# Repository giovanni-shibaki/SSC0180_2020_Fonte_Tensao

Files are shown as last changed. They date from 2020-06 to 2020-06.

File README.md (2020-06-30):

# SSC0180_2020_Fonte_Tensao
Projeto de estudo e desenvolvimento de uma fonte elétrica na matéria de SSC0180 USP 2020. Vamos partir da tensão da tomada (220V ou 127V) e teremos que transforma-la de 127V/220V Corrente Alternada em uma tensão adequada para alimentar nosso circuito. Isto é, de 3V-12V em Corrente Contínua.

## Diagrama da Fonte
### No Falstad
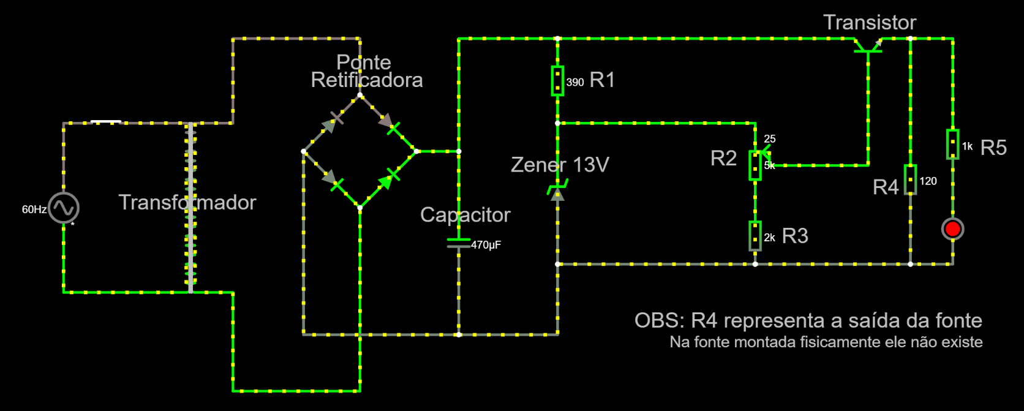
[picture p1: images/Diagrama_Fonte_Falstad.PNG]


### Critérios
* Tensão ajustável entre 3V e 12V 
* Corrente de 100mA
* Baixo Custo

### Componentes e seus Valores
| Componente | Especificações | Valor (Unidade)|
| :--- | :---: | :---  |
| Resistor | 120Ω | [R$0,86](https://tinyurl.com/y8pryj5b) |
| Resistor | 390Ω | [R$0,30](https://produto.mercadolivre.com.br/MLB-1008875897-kit-100un-resistores-2w-de-potncia-escolha-1-valor-ohmico-_JM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) |
| Resistor | 1kΩ | [R$0,13](https://produto.mercadolivre.com.br/MLB-1399314776-resistor-1k-ohms-100-unidades-_JM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) |
| Resistor | 2kΩ | [R$0,16](https://produto.mercadolivre.com.br/MLB-1359755617-100un-resistor-18w-2k-2000-ohms-_JM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) |
| Potenciômetro | 5kΩ | [R$1,09](https://www.baudaeletronica.com.br/potenciometro-linear-de-5k-5000.html) |
| Capacitor | 470μF | [R$1,70](https://produto.mercadolivre.com.br/MLB-845022301-10x-capacitor-eletrolitico-470uf-x-25v-470-uf-470uf-b-_JM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) |
| Transistor | 15V  e 500mA | [R$1,12](https://produto.mercadolivre.com.br/MLB-939476869-10x-transistor-2sa1015-a1015-_JM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) |
| Diodo de Zener | 0,5W | [R$0,21](https://produto.mercadolivre.com.br/MLB-1395521239-diodo-zener-13v-05w-1n5243-lote-de-100-pecas-_JM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) |
| Ponte Retificadora| 1000V e 2A | [R$1,96](https://produto.mercadolivre.com.br/MLB-1151520283-ponte-retificadora-2w10-2a-1000v-lote-com-10-pecas-_JM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) |
| Transformador | 15V e 500mA | [R$25,90](https://www.filipeflop.com/produto/transformador-trafo-15v-500ma-bivolt/) |
|LED | Difuso 3mm | [R$0,20](https://www.eletrogate.com/led-difuso-3mm-vermelho) |
|Switch | 250V e 3A | [R$8,00](https://tinyurl.com/y9v33gzg) |
| **Custo Total** | | **R$41,63** | 
<!-- | Fios (jumper)     | 15V e 500mA         | R$            | -->
<!-- | Protoboard        | 830 Pontos          | R$            | -->
### Justificativa dos Componentes Escolhidos
1. Resistores
    * R1 (390Ω) : Limita corrente eletrica que passa pelo Zener  
    * R2 (5kΩ)  : Potenciômetro , regula a corrente de base que vai para o transistor, assim a fonte varia de 12v e 100mA para 3v e ~24mA
    * R3 (2kΩ)  : Como está ligado em série com o potênciometro ele também serve para regular a tensão de base que vai para o transistor e consequentemente a voltagem de saída de nossa fonte.
    * R4 (120Ω) : Auxiliar para a regulagem da tensão de saída (é como a saída da fonte). Representa a saída da Fonte no pior caso (120ohms)
    * R5 (1kΩ)  : Deixa a corrente adequada para o funcionamento do LED
2. Capacitor
    * Serve para estabilizar a tensão do circuito
    * Nosso circuito chega em um pico de 15V, então o de 25V é mais do que suficiente.
3. Transistor
    * Atenua a corrente e a tensão que vai para a saída do sistema através da corrente de base de 1mA que passa pelo potenciometro R2 e a resistência R3.
4.  Diodo de Zener
    * Equivale a : 13V e 20mA. Isso pois (P=i*U) P = 13V * 0,02A = 0.26W, então um diodo de 0,5W é mais do que suficiente
    * É importante ressaltar que: a corrente que passa pelo diodo é a corrente que atravessa o resistor 390 Ohm (R1: 6mA ) menos 3mA que vai pro transistor ==> 3mA passando no Zener
    * Como opera inversamente, ele mantem o valor da tensão máxima, no caso os 13V.
5. Ponte Retificadora
    * Transforma AC em DC que sai de nosso transformador
6. Transformador
    * 127V ou 220V através de chave seletora no circuito. Potência de 7,5W
7. LED
    * Indica que o circuito está ligada, algo trivial
<!-- 8. GND
    - O ground faz o escape da energia para um local seguro, por precaução -->
<!-- 8. Fios
    - Conectam os componentes do circuito  -->
<!-- 9. Protoboard
    - Base de construção de circuitos. Escolhida por praticidade, não necessita soldar para conectar componentes do circuito -->

## Circuito no Falstad
* http://tinyurl.com/ycns7so6

## Projeto do Esquemático e do PCB no EAGLE
### Esquemático
O projeto esquemático é análogo a uma "planta" de um circuito. Nele são ilustrados os componentes, valores e suas conexões no circuito.<br>
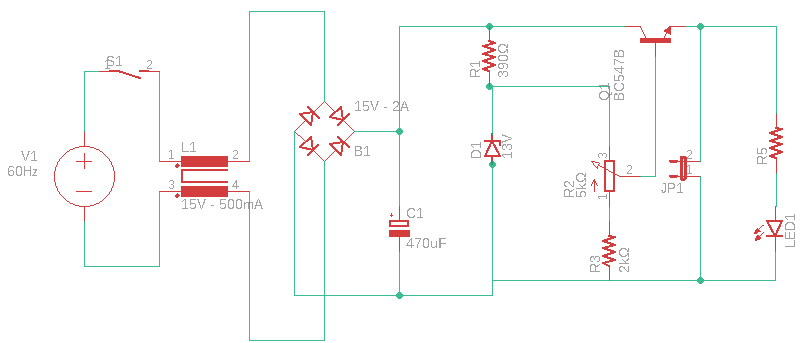
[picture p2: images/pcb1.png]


### PBC ( _Printed Circuit Board_ )
O PCB é uma placa dedicada a expressar as conexões de um determinado circuito. Permitem uma instalação precisa, compacta e confiável dos componentes. <br>
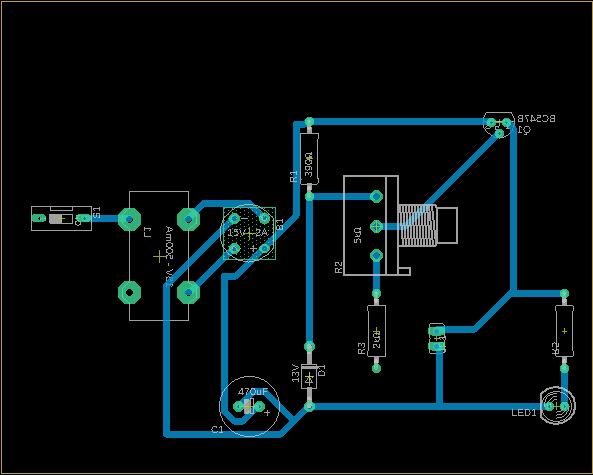
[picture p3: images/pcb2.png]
<br>
OBS: os arquivos pertinentes ao projeto realizado no EAGLE podem ser encontrados neste mesmo repositório, na pasta "eagle"

## Fotos do Circuito (EM BREVE)
` incluir fotos da placa/protoboard`

## Vídeo Explicativo
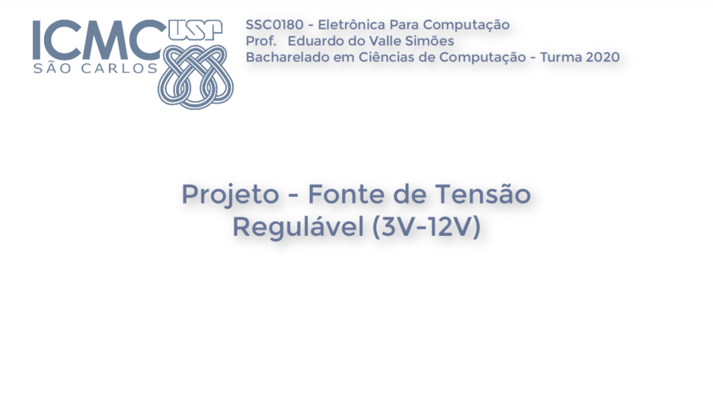
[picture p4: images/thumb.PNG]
Imagem da Thumbnail (https://youtu.be/bJFIhHIyaTQ)


## Participantes

* **Giovanni Shibaki Camargo** - [giovanni-shibaki](https://github.com/giovanni-shibaki)

* **Melissa Motoki Nogueira**  - [mmotokki](https://github.com/mmotokki)

* **Pedro Kenzo Muramatsu Carmo** - [Muramatsu2602](https://github.com/Muramatsu2602)

## Agradecimentos

* Agradecimentos ao [Prof Simões](https://github.com/simoesusp) pela oportunidade de realizar o projeto.
* Agradecimentos à equipe pela dedicação e afinco nestes tempos anômalos
* Special thanks to [Mehdi Sadaghdar](https://www.youtube.com/watch?v=j4u8fl31sgQ&list=PLr_CZLgMkHeXc_45uIgYutY0m6fqmI5du), whose insighful videos made learning electronics more enjoyable!

## Observações

* O circuito montado no Falstad e no Eagle são baseados em um transformador de 127V. Caso 220V fosse utilizado algumas possíveis mudanças poderiam ser necessarias, podendo ser utilizado um Capacitor de 1000uF.
* O embasamento teórico para a elaboração da fonte pode ser encontrada no [livro](https://www.amazon.com.br/Eletr%C3%B4nica-B%C3%A1sica-Computa%C3%A7%C3%A3o-Annibal-Junior/dp/8521616996) base da disciplina
* A organização do projeto, bem como reuniões e discussões, pode ser conferida neste [doc](https://docs.google.com/document/d/1Gu77hdx1NdPrP7V1o1ucyJgEMdmdFqv-v6fdKn2zFD0/edit?usp=sharing)

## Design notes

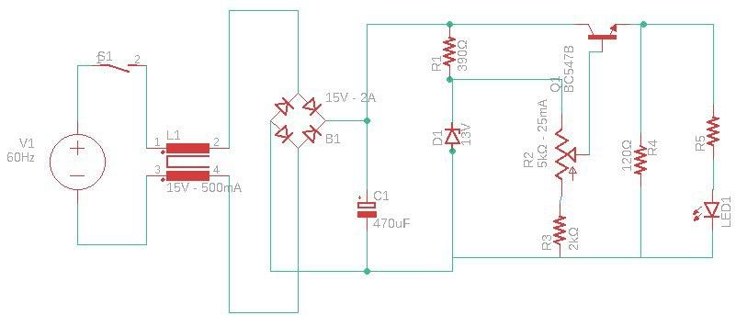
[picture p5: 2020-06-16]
images/pcb2.jpg

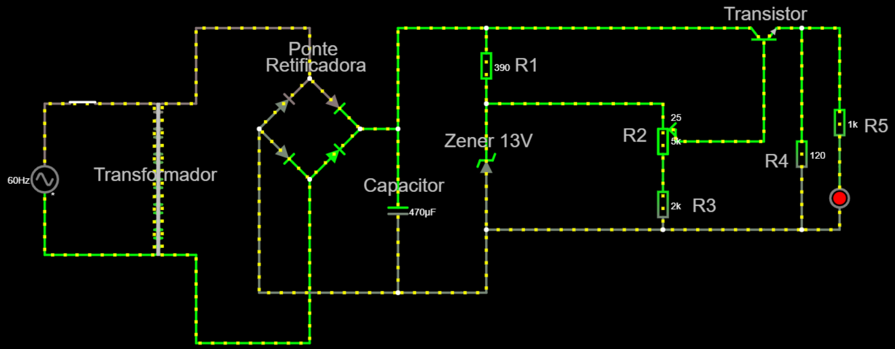
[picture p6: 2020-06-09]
images/DiagramaFonte.PNG

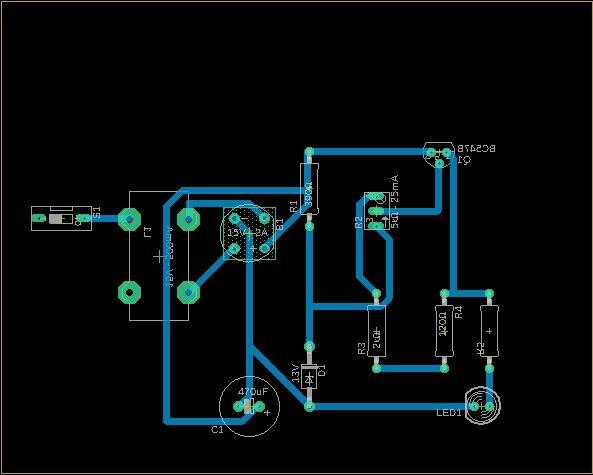
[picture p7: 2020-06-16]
images/pcb1.jpg

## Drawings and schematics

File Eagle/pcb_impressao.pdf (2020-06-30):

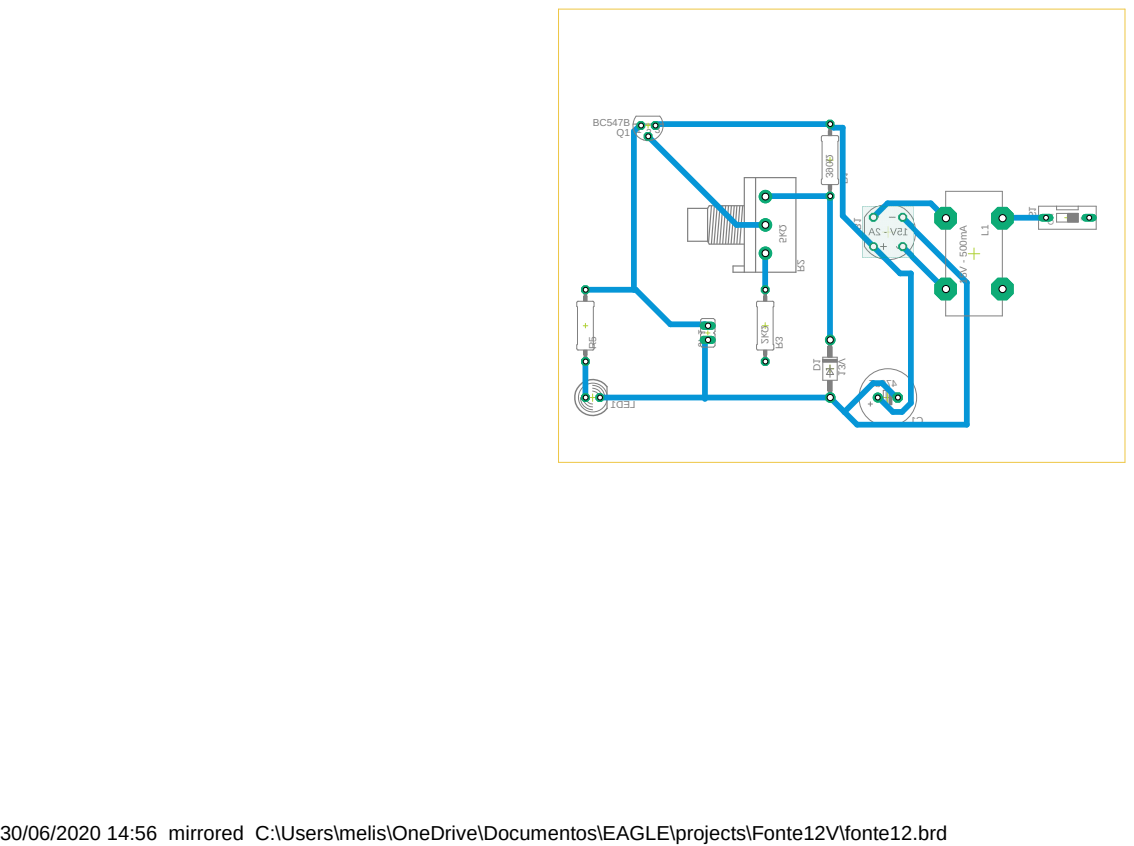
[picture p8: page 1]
15V ⁻ ⁵⁰⁰mA

30/06/2020 14:56 mirrored C:\Users\melis\OneDrive\Documentos\EAGLE\projects\Fonte12V\fonte12.brd

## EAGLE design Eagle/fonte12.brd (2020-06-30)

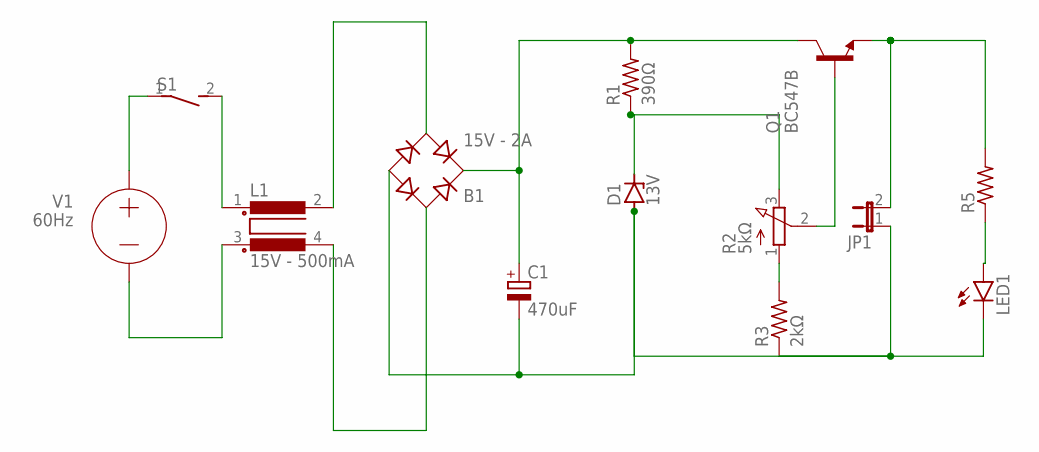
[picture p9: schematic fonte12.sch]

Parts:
B1: 15V - 2A; RB1A
C1: 470uF; E3,5-10
D1: 13V; DO41Z10
JP1: JP1E; JP1
L1: 15V - 500mA; B2
LED1: LED5MM
Q1: BC547B; TO92
R1: 390Ω; 0309/12
R2: 5kΩ; 3RP/1610N
R3: 2kΩ; 0309/12
R5: R-US_0309/12; 0309/12
S1: DS01E; DS-01

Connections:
unnamed: R2.1 (A), R3.2
unnamed: JP1.2, Q1.1 (E), R5.2
unnamed: B1.AC2, L1.2
unnamed: B1.AC1, L1.4
unnamed: B1.+, C1.+, Q1.3 (C), R1.2
unnamed: B1.-, C1.-, D1.A, JP1.1, LED1.K (C)
unnamed: D1.C, R1.1, R2.3 (E)
unnamed: LED1.A, R5.1
unnamed: L1.1, S1.2
unnamed: Q1.2 (B), R2.2 (S)

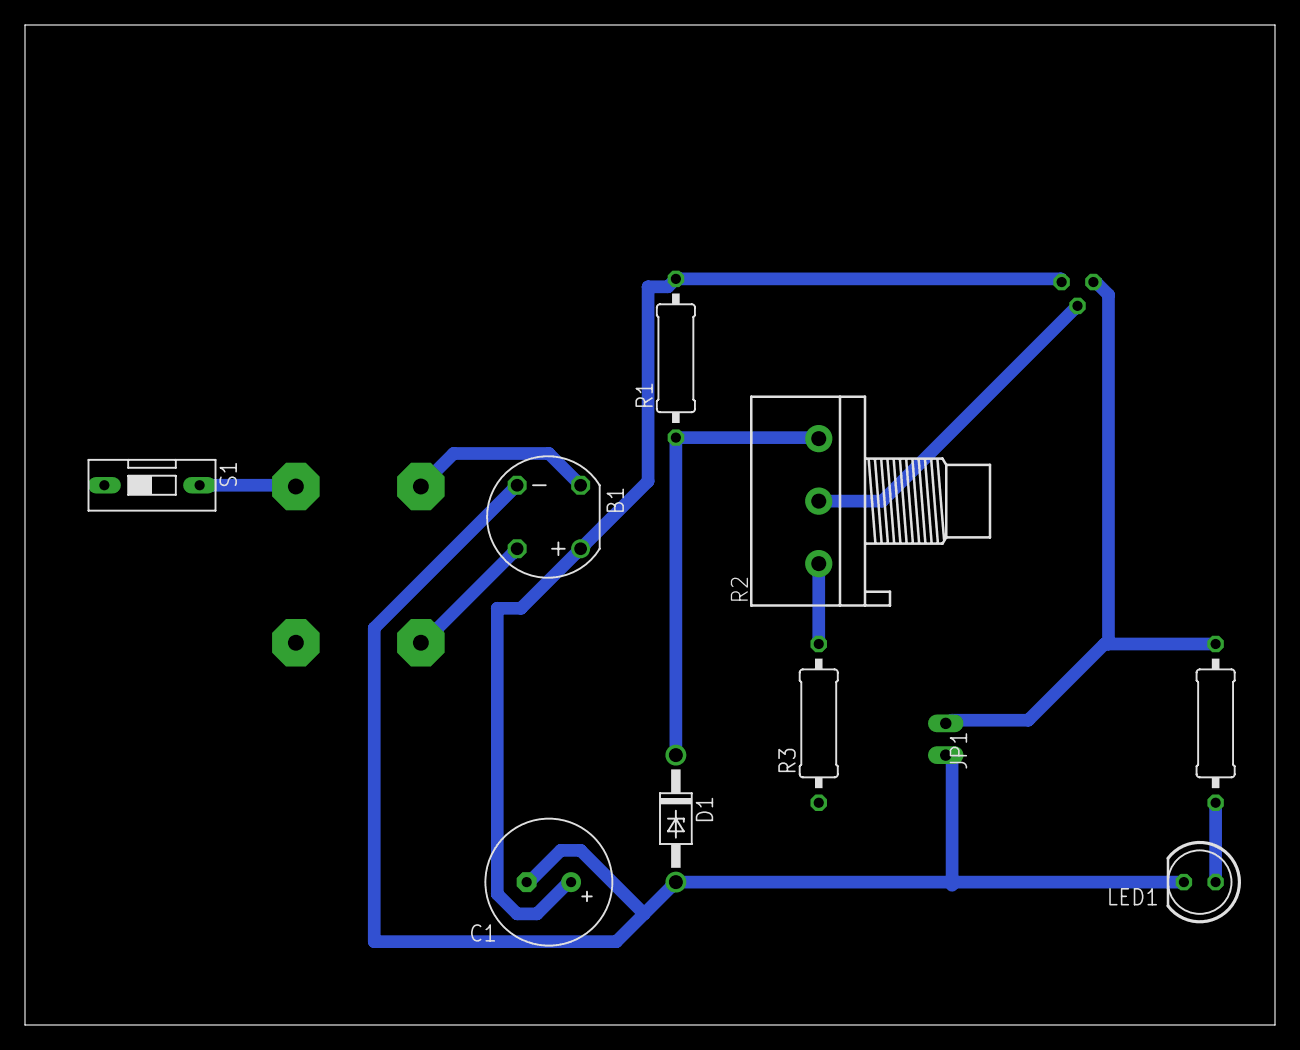
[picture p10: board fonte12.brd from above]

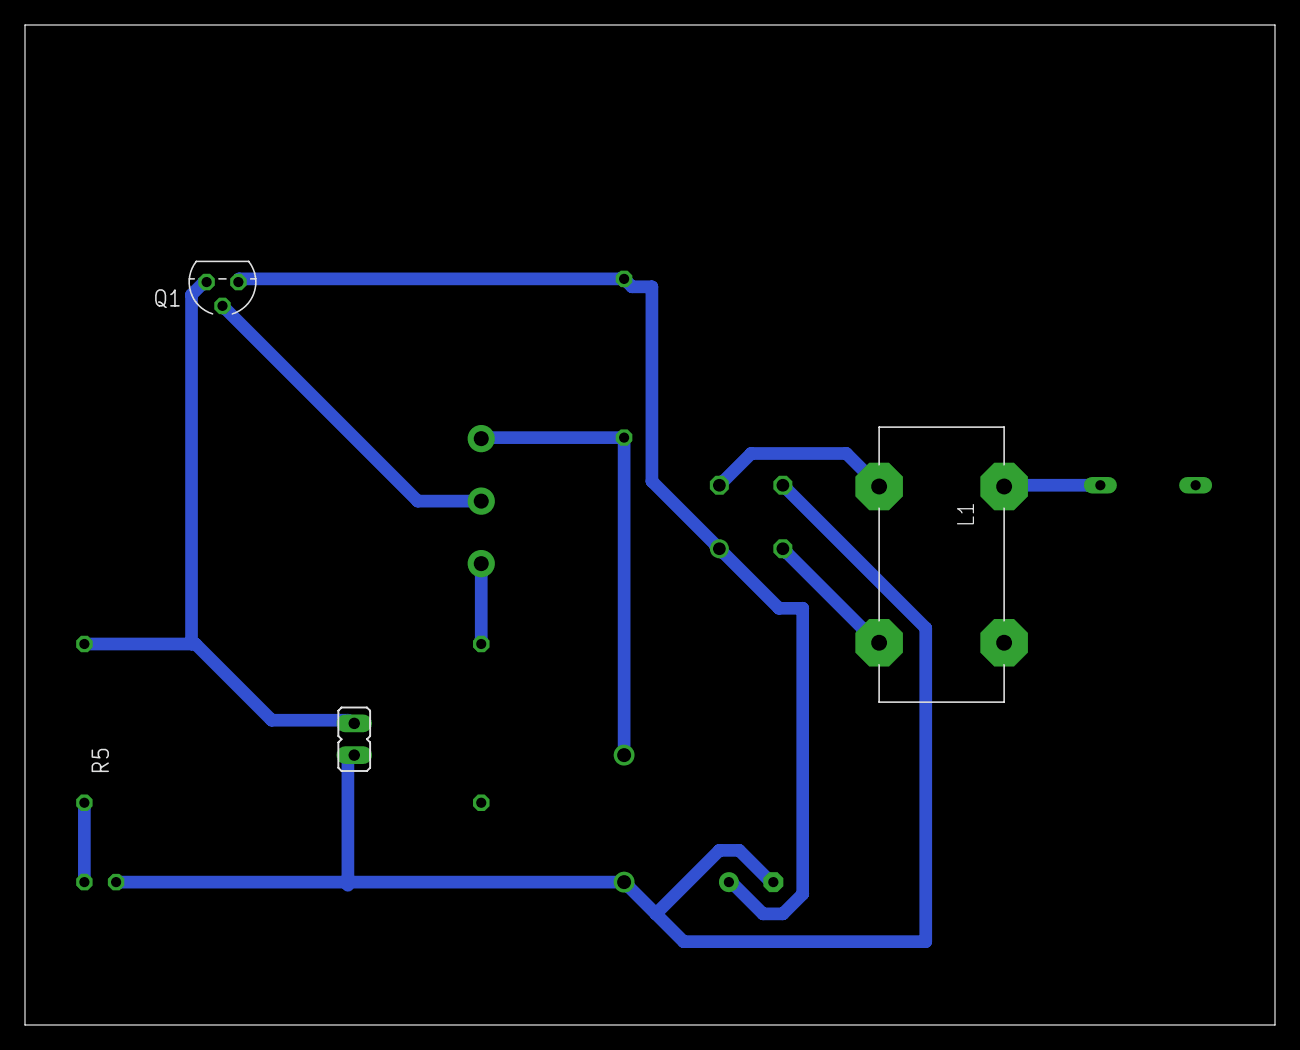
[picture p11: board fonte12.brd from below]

Board: 2 copper layers, 100.0 x 80.0 mm, 12 parts (3 on the bottom side), 10 nets.

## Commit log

2020-06-16 Arquivos EAGLE
    Upload dos arquivos (sch, brd, epf e afins) do projeto do Eagle.
    [fonte12.brd, fonte12.sch]
2020-06-16 Novas imagens
    Troquei o modelo do potenciômetro, para ficar mais semelhante ao do prof.
2020-06-16 Atualização
    Atualizei os arquivos do circuito, uma vez que precisei trocar o modelo do potenciômetro.
    [fonte12.brd, fonte12.sch]
2020-06-16 PDF de impressão
    Arrumei, selecionando a opção 'mirror'
2020-06-30 Diagrama no Falstad com observação para R4
2020-06-30 Ajustes pós-apresentação
    Adicionou-se a saída do sistema no lugar do R4
    [fonte12.brd, fonte12.sch, untitled.sch]
